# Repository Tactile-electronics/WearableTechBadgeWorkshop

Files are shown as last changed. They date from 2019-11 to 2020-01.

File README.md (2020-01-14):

## Wearable Technology Badge Workshop



Make a small interactive rechargeable wearable badge over 4 weeks to get you started in the world of wearable technology. Designed to give you an understanding of basic fundamentals in electronics, embroidery and coding in the versatile progamming language micropython to control interactive intimate wearables.  We'll use DIY conductive yarn pressure sensors and variants of low cost ESP8266 development boards that can help you deploy all kinds of wearable (and non-wearable) technology.

With this experience you'll be able to prototype and deply wearable tech for art, performance, fashion, product development. It's a chance to share your ideas with peers and meet other members of the DoES Liverpool community and get to know our facilities for the future.

All materials are provided, with extensive workshop notes, reference and resources here plus your own kit featuring an ESP8266 development board, Sublimation printed sensor, single and 6-ring NeoPixels, and a rechargeable battery pack you can for your next project.

Under 16s must be accompanied by a parent or guardian, suitable for ages 12 and up.

### Structure

 1. [Analog Textile Sensor making](#session-1)
 1. [LED & NeoPixel control with ESP8266 and MicroPython](#session-2)
 1. [Analog Sensor & ESP8266](#session-3)
 1. [Advanced ESP8266, sensor & LED control & Wearable Badge constructing](#session-4)

### Session 1

Make & test an analog textile sensor to understand the basics of electrical resistance and the flow of current in a simple circuit.




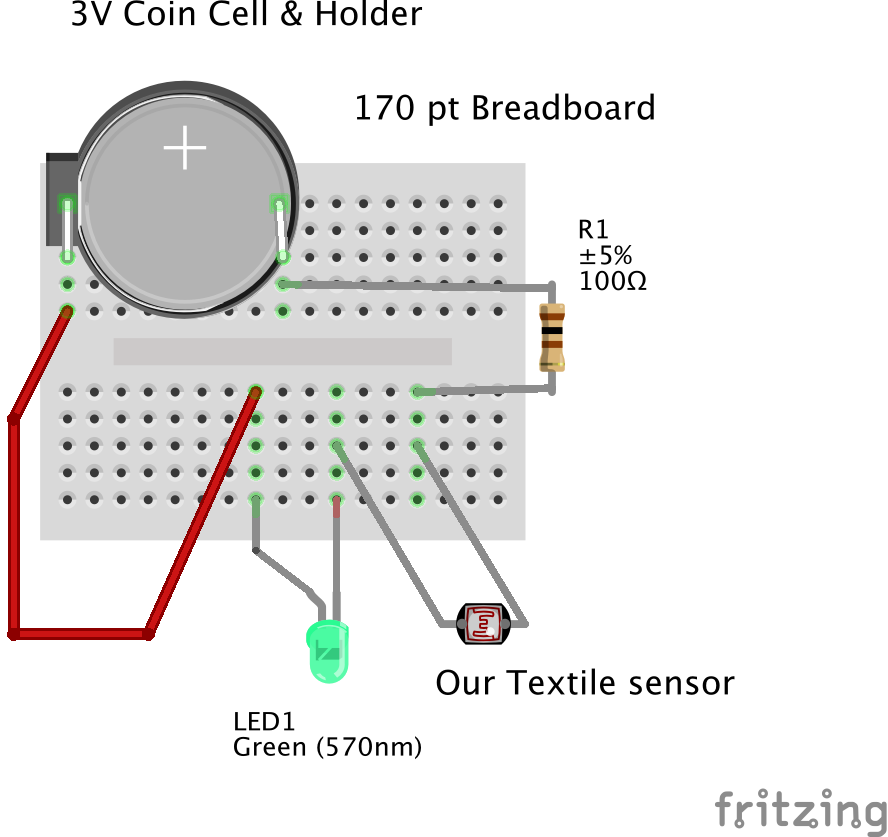
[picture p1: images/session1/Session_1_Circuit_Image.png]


Our breadboard lets us easily connect electronic components and wire of the correct gauge clearly without the components falling out. They are how people prototype a circuit, and quite often you will rewire it in a way that's more robust and permanent or even design and make your own printed circuit boards (PCBs). On these mini 170-point breadboards there are 2 columns of 17 rows of 5 pins. Each 5 pin set on a  row are connected electrically so current flows through components. We generally dont use voltage over 12V when using these breadboards so we never have anything close to mains voltage. We are not even going above 3.7V with our wearables!

Follow the pictures below to make the circuit and compare it with the circuit diagrams provided. That's how you'll find diagrams on the internet and in electronics books, so it's worth having a look at those and doing some further research.

#### Circuit

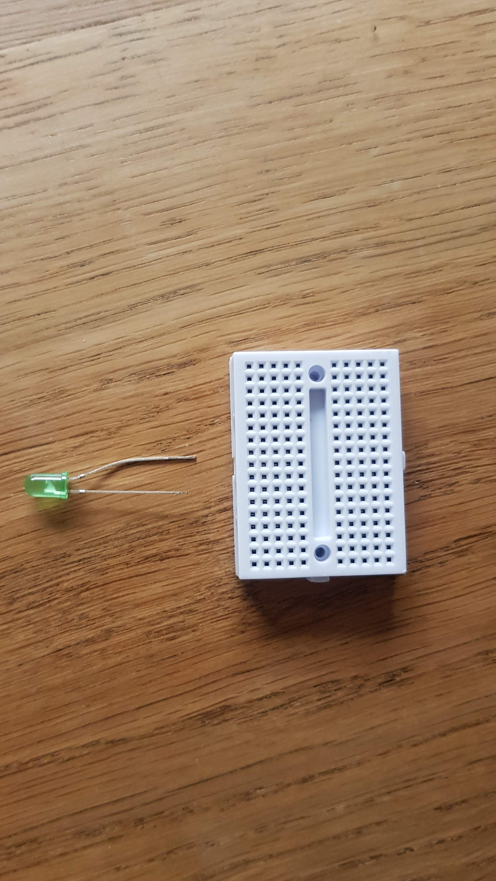
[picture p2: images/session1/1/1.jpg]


Insert your LED. It matters which way the LED goes in; it's got a negative cathode `-` and a positive anode `+` if you get it wrong you can damage it. The long leg of the LED is `+'ve`, the shorter leg, the cathode, is `-'ve'`

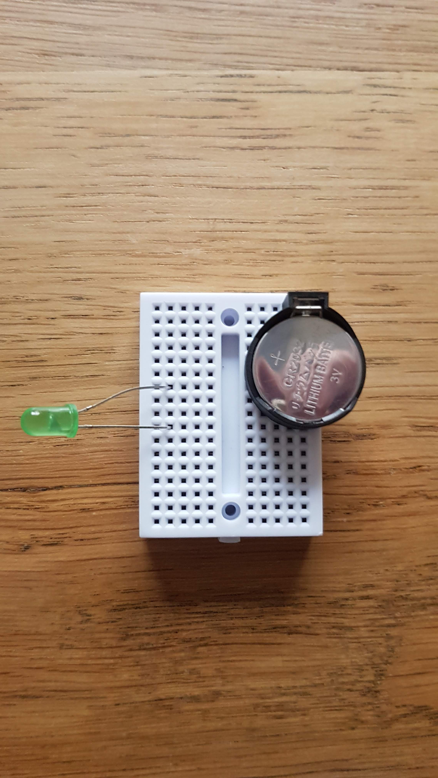
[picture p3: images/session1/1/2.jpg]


Add your coin cell holder and coin cell. Be careful you understand the `+'ve` and `-'ve` cathod and anode. The `+` on the coin cell should be visible facing up, the Flat side of the coin cell holder is `-`

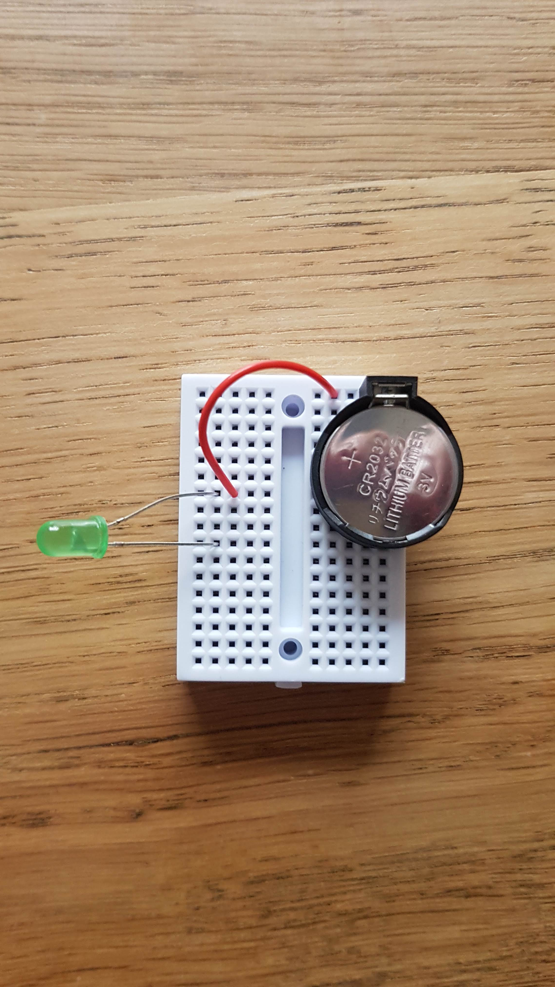
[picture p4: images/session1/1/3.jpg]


Add a red jummper wire connecting the long leg `+` anode of the LED with the `+` anode of the coin cell holder, the pin nearest the flat side of the holder

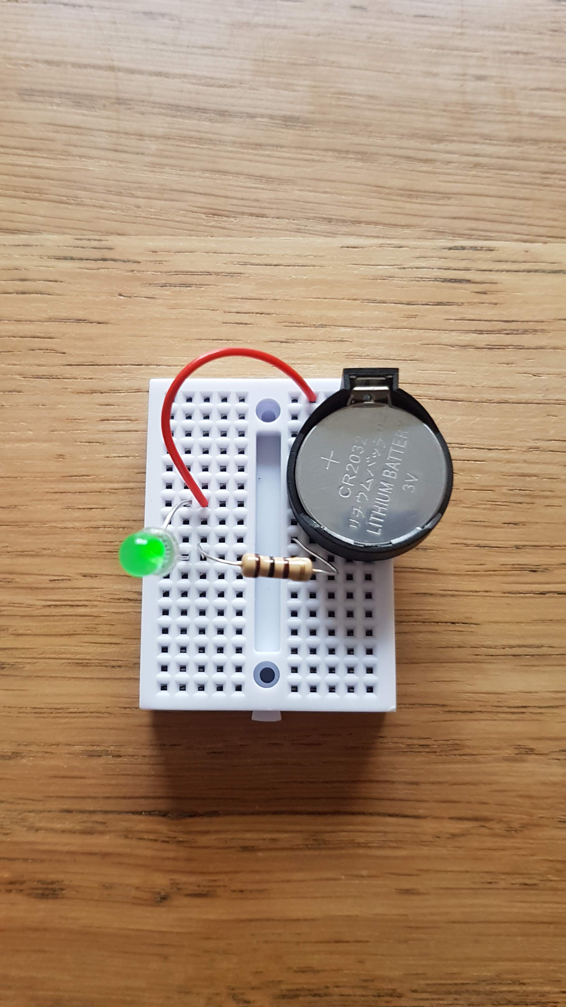
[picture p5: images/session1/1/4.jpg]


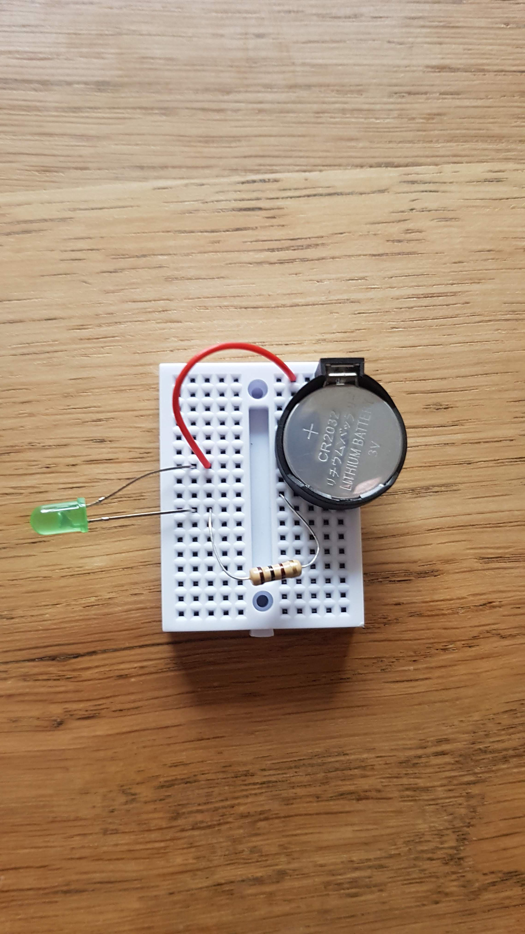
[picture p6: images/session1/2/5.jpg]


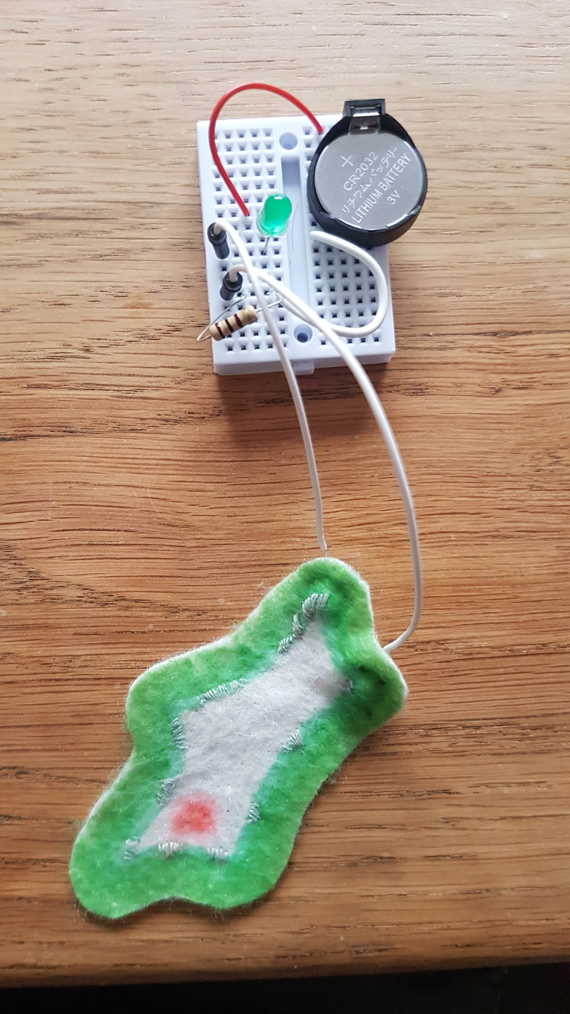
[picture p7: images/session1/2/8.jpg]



Stitch onto the felt with the resistive thread, leaving a long piece on the back of the felt before your first stitch




Make some stitches close together some can be touching but not overlapping or on top of one another


Continue until you have stitched along the back of the design, its fine to leave gaps. Leave a piece trailing at the other end. 




Tie a piece of conductive thread to one end of the stitching
Stitch and add a snap fastener, then repeat at the other side with conductive thread.


Solder wires onto the other side of the snap fasteners.


Clip the fasteners together

#### Component List

Component|No.|Source|Produced|Notes
--|--|--|--|--
170 point<br>mini breadboard|1|DoES|China|For prototyping
3V CR2032 coin cell battery|1|Ebay|
Two Pin Button|1|[Taydae Electronics](https://www.taydaelectronics.com/tact-switch-6-6mm-5mm-through-hole-spst-no.html)|China|simple breadboard compatible button
CR2032-compatible Watch Battery holder|1|[BatteryHolders.com](http://batteryholders.com/part.php?pn=BC2032-E2&original=CR2032&override=CR2032)|China|Easy breadboarding holder
Red Stripped solid core 22AWG wire|1|[Farnell](https://uk.farnell.com/c/cable-wire-cable-assemblies/hook-up-wire?wire-gauge=22awg)|[Alphawire](http://www.alphawire.com/) New Jersey US|Stripped fits into breadboards easily
Green Stripped solid core 22AWG wire|1|[Farnell](https://uk.farnell.com/c/cable-wire-cable-assemblies/hook-up-wire?wire-gauge=22awg)|[Alphawire](http://www.alphawire.com/) New Jersey US|Stripped fits into breadboards easily
Resistor 100 Ohm|1|Ebay|China|Resistor; fits anyway round (polarity doesn't matter)
Resistor 10K Ohm|1|Ebay|China|Resistor; fits anyway round (polarity doesn't matter)

This first step develops the basics of a pressure sensor; we can refer to more complex and accurate sensors and reflect on their usage.

### Further Reading

You can read about an alternative form of pressure sensor using [Velostat](https://www.adafruit.com/product/1361) that Laura made for another workshop using a similar microcontroller [Microbit](https://www.microbit.org/) belwo, that also runs micropython the programming language we are using to control our sensors and LED's.

[Pressure sensor build](https://github.com/DoESLiverpool/what-does-health-look-like/tree/master/pressure-sensor)

### Session 2






Flash LEDs in response to our sensors using micropython on ESP8266

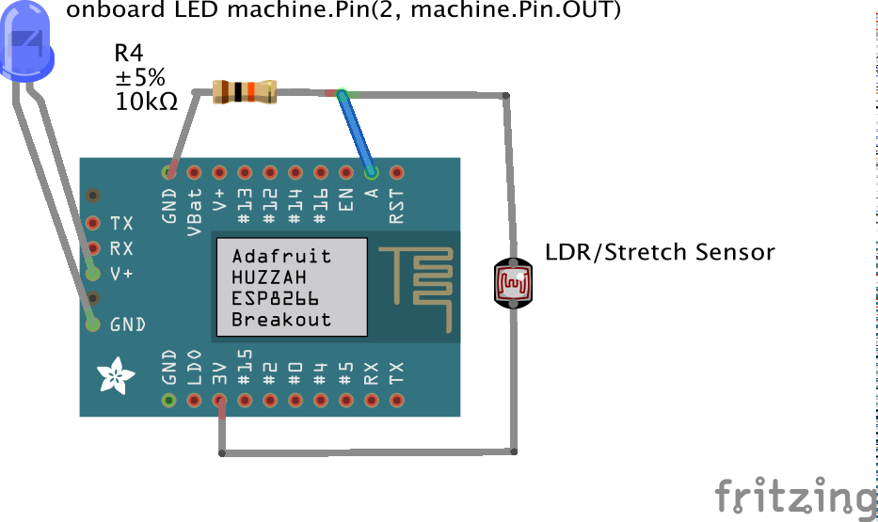
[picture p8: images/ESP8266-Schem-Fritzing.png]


#### Micropython and the ESP8266

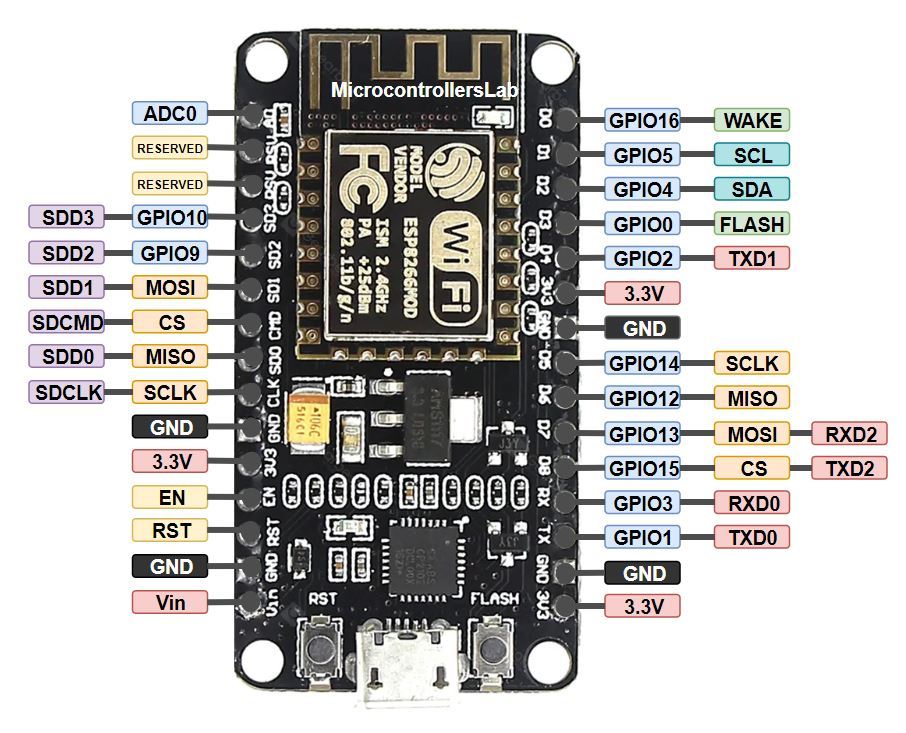
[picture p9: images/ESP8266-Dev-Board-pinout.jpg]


We're using the a few variant breakout boards of the ESP8266 like the WeMos D1 Mini Development Board in the diagram above or the bigger [ESP-12E-CP2102](https://www.ebay.co.uk/itm/Esp8266-Esp-12E-Cp2102-Wifi-Network-Development-Board-Module-For-Node-Mcu-GD/264530529453) variant which you can see above with its `GPIO` pin arrangement. We'll be using these in our workshops and you'll be able to take them home.

You can refer to the [MicroPython tutorial for ESP8266](https://docs.micropython.org/en/latest/esp8266/tutorial/index.html#micropython-tutorial-for-esp8266) for full details, but we've selected.

#### Connecting up

You'll need `CP2102` USB Module drivers to work with our ESP8266's which you can get from our friends at [Shrimping.It](https://shrimping.it/drivers/) and we'll provide them in the workshop from [here](drivers)

Linux distributions include built-in CP2102 drivers, although Linux user accounts may need membership of the 'dialout' or 'serial' permission groups to access the device.

#### Using PUTTY

To get connected on Windows you might be best using PUTTY

Windows Download [PuTTY](https://putty.org/) to connect your ESP8266 to your computer over USB-Serial and be able to send commands to control and set it up.

Linux - Use the built in `screen`, `minicom` or Putty using `$ sudo apt-get install putty` in your Linux Terminal. I'd recommend screen.

Mac - Download [PuTTY](https://putty.org/) or use the built-in `Applications/Terminal` and `screen`

#### Using `screen`

On macos and Linux you can just use a Terminal and `screen`. If your linux doesnt have screen install with `sudo apt-get install screen` or `brew install screen` on a mac after setting up [HomeBrew](https://brew.sh/)

`$ ls /dev/tty*`

to list your usb devices.

`$ screen /dev/device_name baud-rate`
is the general format.

`$ screen -S wearable /dev/tty.SLAB_USBtoUART 115200`

Then press enter and you'll see the python prompt. You are now connected to your ESP8266!

### Micropython Command Walkthrough

In python like we saw earlier, we import the tools we need to do the various things we need, with microbit, most of it is already there.

Get the machine module to control our ins and outs

`import machine`

Lets define a Pin as an output, using the onboard Pin no. 2

`ledPin2 = machine.Pin(2, machine.Pin.OUT)`

This should turn the LED on!

Now try:

`ledPin2.off()`

Annoyingly defining the pin like this means off has no effect, but we can use Signal to abstract away this.

`from machine import Signal`
`Led2 = Signal(ledPin2, invert=True)`

now things will work more intuitively if we use Led2 instead!

`Led2.off()`
`Led2.on()`

Ok now lets read one of our sensors. Wire up following the diagram above.

The ADC (analog to digital conversion) Pin is labelled A0 on your board and we will need the ADC class to make it work

`from machine import ADC`
`adc = ADC(0)`
`adc.read()`

Will return a value. Ok lets get it to read the values until we press `ctrl +c`. We will use a simple loop using `while`

`while True:` press return and you will see `...` and your cursor will indent automatically.

`adc.read()`

Now press return, and you get another indent, return a few time indicates thats the end of that loop and it will then execute the code.

Play with your sensor and watch the numbers change. Cool eh? Bit fast though, lets slow it down with `time`

`import time`

Now we can use `time.sleep(seconds)` to wait before reading the pin again.

```
while True:
    adc.read()
    time.sleep(0.5)
```

Now lets use that to blink our LED

```
while True:
    Led2.on()
    time.sleep_ms(adc.read() * 10)
    Led2.off()
    time.sleep_ms(adc.read() * 10)
```

Ok but higher resistance, bigger stretch or pressue is slowing our flashes. WE can flip it round

```
while True:
    stretch = 500 - (adc.read() *10)
    Led2.on()
    time.sleep_ms(stretch)
    Led2.off()
    time.sleep_ms(stretch)
```

### Making Permanent Changes

You need to make a `main.py` file on the board. To do this you need to write your code and copy it into the command line prompt of the ESP

So copy the text from [main.py](main.py).
Then in your open console for your ESP:

`f = open('main.py', 'w')`

then use **paste mode**: move your cursor to just after the set of 3 quotes (they are essential) and press `ctrl + e` and you will be given a few options: right click paste or shortcut `cmd + v` to paste in your text for the programme. Then finish and call `f.close()` to close and save the file.

```
f.write('''paste_your_text here''')
f.close()
```

Check its there with

`import os`
and
`os.listdir()` to check it's there.

Now reboot, and if your file is correct it will run the `boot.py` script (don't worry about that for now it just sets up the board and python) and then your `main.py` file should run!

We generally prototype code by running it line by line, a bit like having a *conversation* with your board. I like the way that weirdly makes you feel more connected to it and we think it might help you learn.

Then you can write your `main.py` file based on these conversations, have a look at our [`main.py` template](main.py) to see how our 'conversations' we've had here looks as a complete python script. (it is like writing the script of the conversation you've alread had :smile:

### Ampy

There are other methods to upload more complex files you can look at like [ampy](https://github.com/scientifichackers/ampy) so we will try setting this up for you.

 * `ampy --port /dev/MY_PORT_NAME ls` Lists files

 * `ampy --port /dev/MY_PORT_NAME put examples/circle/lights.py` Puts the file on the board

 * `ampy --port /dev/MY_PORT_NAME rm examples/circle/lights.py` Removes the file on the board

### PWM output and Controlling LEDs

We've taken from [this tutorial by Random Nerd Tutorials](https://randomnerdtutorials.com/esp32-esp8266-pwm-micropython/)

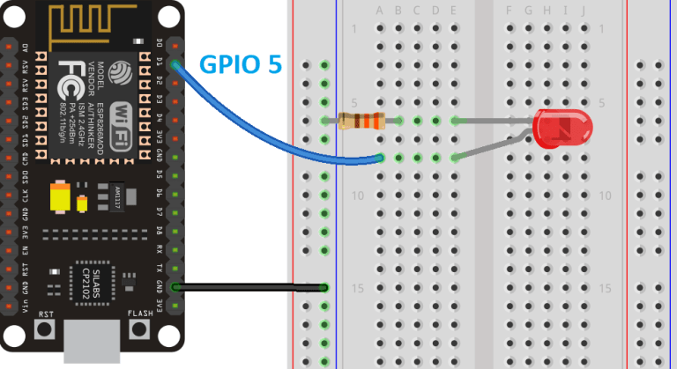
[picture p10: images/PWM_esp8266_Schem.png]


For this example, wire an LED to your ESP board. We’ll wire the LED to `GPIO 5` (marked as `D1` on your board), but you can choose another suitable PWM pin

Here’s the script that changes the LED brightness over time by increasing the duty cycle.

```
from machine import Pin, PWM
from time import sleep

frequency = 5000
led = PWM(Pin(5), frequency)

while True:
    for duty_cycle in range(0, 1024):
    led.duty(duty_cycle)
    sleep(0.005)
```

Also refer to these tutorials
 * [PWM Tutorial](https://docs.micropython.org/en/latest/esp8266/tutorial/pwm.html#pulse-width-modulation)
 * [Fading an LED](https://docs.micropython.org/en/latest/esp8266/tutorial/pwm.html#fading-an-led)

### NeoPixels

To wire up you just connect `3.3V`(marked as `3V3` on your board) to `+VCC` on the neopixel, `GND` (marked `GND` on your board) to `GND` on the neopixel, and `GPIO5` (marked as `D1` on your board to the `IN` or `DIN` on the neopixel. NeoPixels have got all the resistors on board so you wont need to protect your Digital pins when using them.

NeoPixels are addressable RGB LEDs and micropython has a library module just for that! Add the [`lights.py`](https://github.com/cheapjack/WearableTechBadge/blob/master/examples/circle/lights.py) script to your board and with a quick

```
from lights import *
```

You can run this example code from the [NeoPixel MicroPython Guide](https://docs.micropython.org/en/latest/esp8266/tutorial/neopixel.html):

Once the `lights.py` file is on board, re-log on to your board and you can run these commands:

`cycle()`, `bounce()`, `fade()` and `clear()`

There's also a [`main.py`](https://github.com/cheapjack/WearableTechBadge/blob/master/examples/circle/main.py) you can add so they run on booting the board.

Try writing your own combinations of these functions on a loop and try changing the for loops to cycle through colours

```
from machine import Pin
from neopixel import NeoPixel
import time

n = 7 # Set the number of pixels on your NeoPixel
pin = Pin(5, Pin.OUT)   # set GPIO5 (D1) to output to drive NeoPixels
np = NeoPixel(pin, 7)   # create NeoPixel driver on GPIO0 for 7 pixels
np[0] = (255, 255, 255) # set the first pixel to white
np.write()              # write data to all pixels
np[0] = (0, 0, 0) # set the first pixel to nothing (black)
np.write()              # write data to all pixels

def cycle():
    for i in range(4 * n):
        for j in range(n):
            np[j] = (0, 0, 0)
        np[i % n] = (255, 255, 255)
        np.write()
        time.sleep_ms(25)

def bounce():
    for i in range(4 * n):
        for j in range(n):
            np[j] = (0, 0, 128)
        if (i // n) % 2 == 0:
            np[i % n] = (0, 0, 0)
        else:
            np[n - 1 - (i % n)] = (0, 0, 0)
        np.write()
        time.sleep_ms(60)

def fade():
    for i in range(0, 4 * 256, 8):
        for j in range(n):
            if (i // 256) % 2 == 0:
                val = i & 0xff
            else:
                val = 255 - (i & 0xff)
            np[j] = (val, 0, 0)
        np.write()

def clear():
    for i in range(n):
        np[i] = (0, 0, 0)
    np.write()
```

#### Components

Component|No.|Source|Cost|Notes
--|--|--|--|--
Microusb data cable|1|Ebay|£1.20|
NodeMcu-CP2102-ESP8266 Development Board (narrow profile)|1|[AliExpress](https://www.aliexpress.com/item/32665100123.htm)|£1.93|
Jumper Wires|10|Ebay|£1|
Resistor 4.7k Ohm|1|Ebay|£0.50|
Conductive Yarn|1|Various|£1|
Pressure Sensor|1|Various|£1|
Conductive Rubber|1|Various|£1|
Textile Back|1|Various|£1|
TOTAL|||£8.63|

### Session 3







Re-visit our sensor circuit but this time combine with our ESP8266 boards and controlling our LEDs

### Session 4




Fabricate our amoeba shaped wearable badge and assemble everything using a textile pocket to enclose electronics

 * Enclose the ESP circuit in a customisable fabric template

## TODO

 * [x] Re-solder the press studs

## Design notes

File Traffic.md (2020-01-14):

#### Traffic light

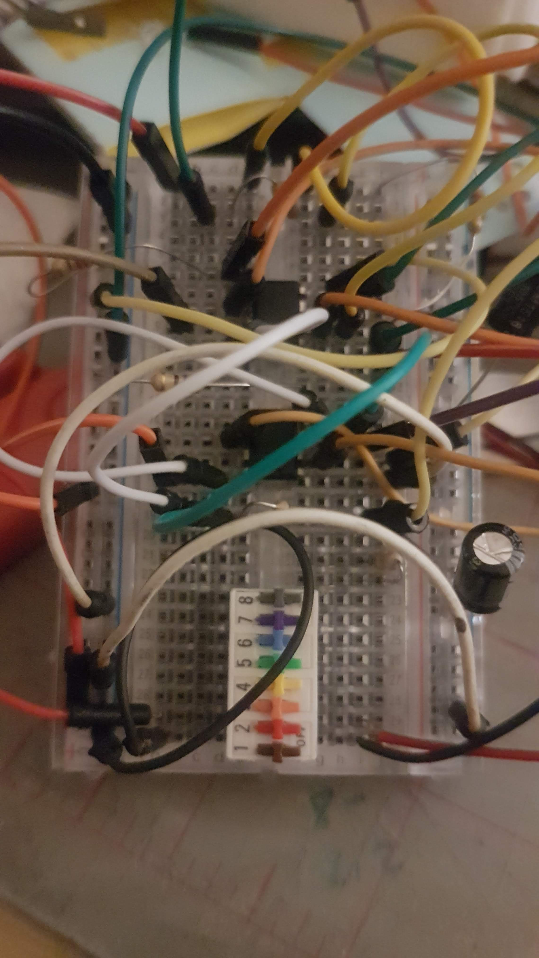
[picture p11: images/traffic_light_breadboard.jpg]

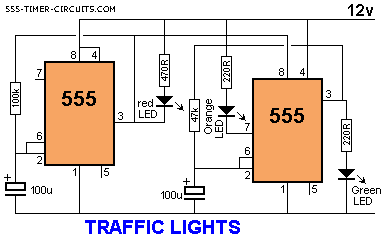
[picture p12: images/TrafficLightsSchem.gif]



Component|No.|Cost|Source|Produced|Notes|SubTotal
--|--|--|--|--|--|--
Mini Breadboard|5|1.196|[Ebay](https://www.ebay.co.uk/itm/5pcs-5x-WHITE-Mini-170-Tie-Point-Solderless-Breadboard-Prototype-Arduino-PIC-PI/262900293129)|China||£5.98
555 Timer Chip|10|0.185|[Ebay](https://www.ebay.co.uk/itm/10-x-NE555P-Timer-DIP-8-IC-Timer-Fast-Delivery-UK-Seller/323925336619)|China||£1.85
9V Battery pack|1||ShrimpingIt surplus|China|Considering replacing with rechargeable LIPO battery
Jumper Wires|40||ShrimpingIt Surplus|
Capacitor 100μF|1||ShrimpingIt surplus|China
Resistor 47K Ohm|1||ShrimpingIt surplus|China
Resistor 470 Ohm|1||ShrimpingIt surplus|China
Resistor 220 Ohm|2||ShrimpingIt surplus|China
Resistor 100k Ohm|1||ShrimpingIt surplus|China

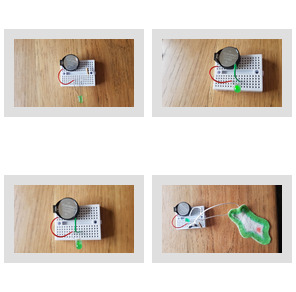
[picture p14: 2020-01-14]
images/session1/2/basic-sensor-circuit-2.jpg

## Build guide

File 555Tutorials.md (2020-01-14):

## 555 Tutorials




Here the 3 of us were interested in exploring physical computing in counterpoint to the previous workshops software layers. We are often frustrated with having to use code to do simple routing or logic that could be done with electronic components. Programming with components means you really understand what components do and how they scale up into Integrated circuits and gives a more intimate understanding of the tech we use.

 * We've used this [555 Timer Learning Site](http://www.555-timer-circuits.com/) to make our circuits

#### 555 Timers

We are using the simple `555` timer chip, one of the most common workhorses of electronics. This integrated circuit creates oscillating square wave signals that can be used to control the flow of voltage in a circuit and so control the logic of say, controlling an LED.

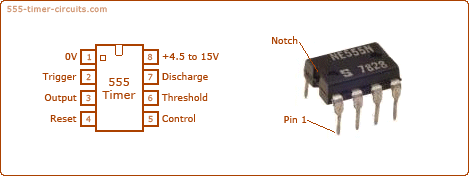
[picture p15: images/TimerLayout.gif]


Find out more on this [555 Timer Circuit website](http://www.555-timer-circuits.com/#circuits)

#### Simple Flasher

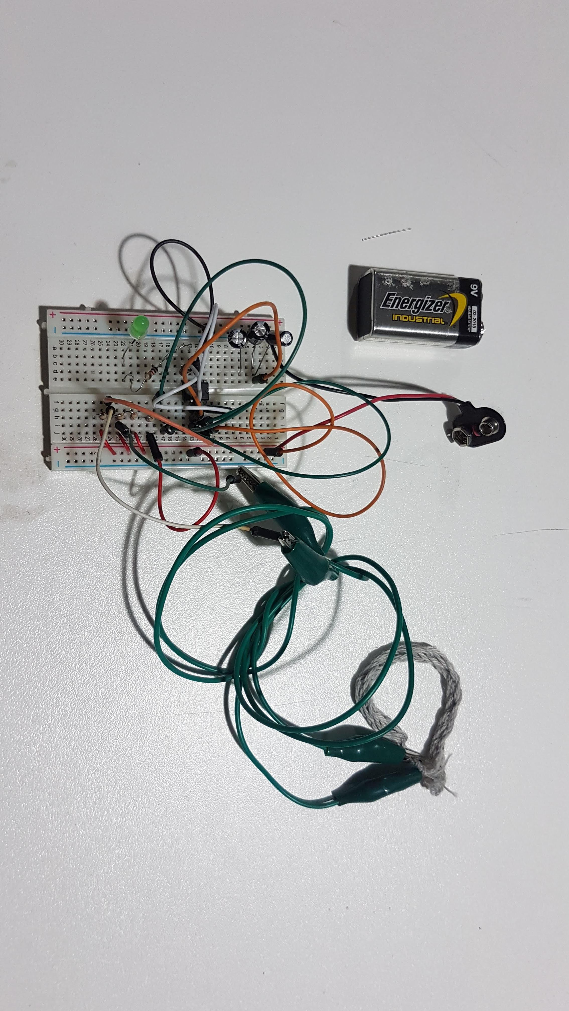
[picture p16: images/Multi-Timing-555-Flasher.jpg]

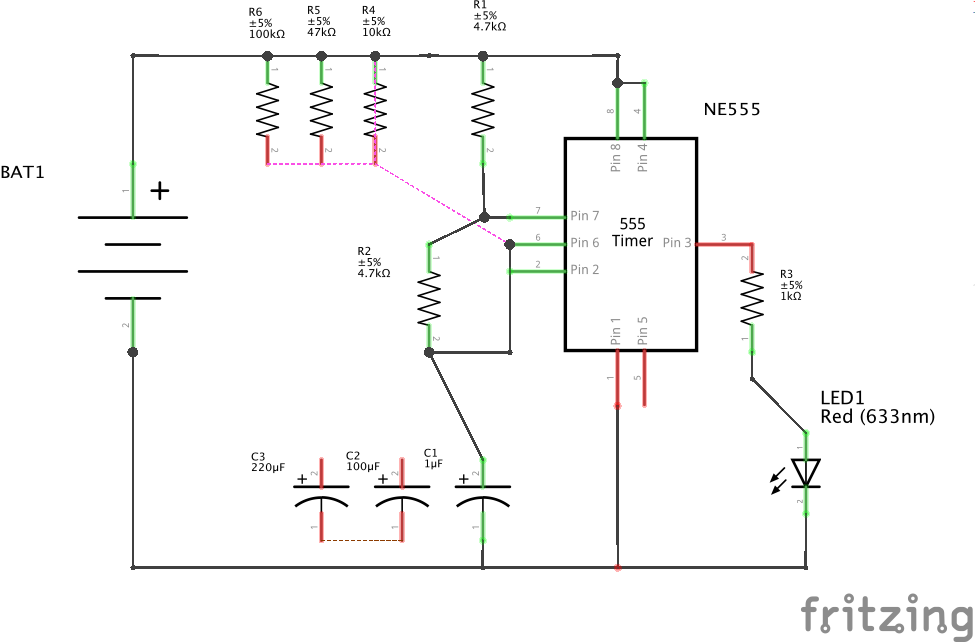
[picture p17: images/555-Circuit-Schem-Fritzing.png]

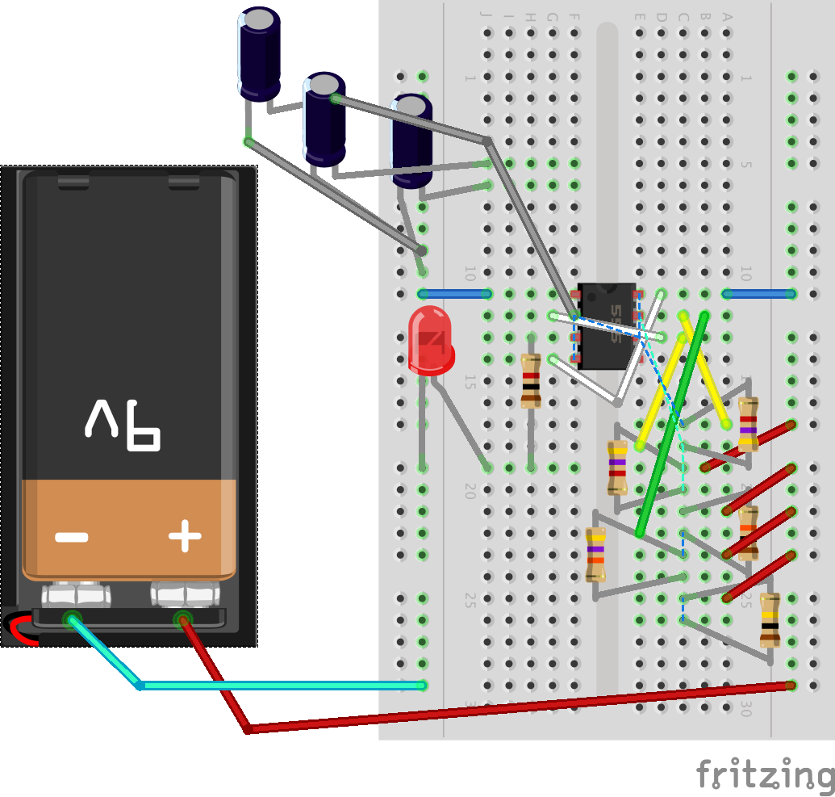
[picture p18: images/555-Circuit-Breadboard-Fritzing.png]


We've made a circuit with an array of capacitors and resistors so you can experiment with the timings

##### Timing LED pulses

 * C1 1µF Capacitor
 * C2 100µF Capacitor
 * C3 220µF Capacitor
 * R1 = 4.7K Ohm
 * R2 = 4.7K Ohm
 * R3 = 1K Ohm
 * R4 = 10K Ohm
 * R5 = 47K Ohm
 * R6 = 100K Ohm

You can work out the timings with this formula

t<sub>on</sub> = 0.69 x C1 x (R1 + R2)
t<sub>off</sub> = 0.69 x C1 x R2

t<sub>on</sub> = Length of high pulse (seconds)
t<sub>off</sub> = Length of low pulse (seconds)
C1 = Capacitance in Farads
R1 = Resistance in Ohms
R2 = Resistance in Ohms

#### Example

t<sub>on</sub>  = 0.69 x 0.0001 x (4700 + 4700) = 0.64 seconds
t on = 0.69 X 0.000220 x (4700 + 4700) = 1.42 seconds

#### Components

Component|No.|Source|Produced|Notes
--|--|--|--|--
300 point Half Breadboard|1|ShrimpingIt surplus|China
9V Battery pack|1|ShrimpingIt surplus|China|Consider replacing with rechargeable LIPO battery
Jumper Wires|9|DoES Surplus|
555 Timer Chip|1|Ebay|China
Capacitor 1μF|1|ShrimpingIt surplus|China
Capacitor 100μF|1|ShrimpingIt surplus|China
Capacitor 220μF|1|ShrimpingIt surplus|China
Resistor 4.7k Ohm|1|ShrimpingIt surplus|China
Resistor 4.7k Ohm|1|ShrimpingIt surplus|China
Resistor 10k Ohm|1|ShrimpingIt surplus|China
Resistor 47k Ohm|1|ShrimpingIt surplus|China
Resistor 100k Ohm|1|ShrimpingIt surplus|China
Conductive Yarn/Rubber/Pressure Sensor|||

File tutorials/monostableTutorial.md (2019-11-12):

---
author: John Hewes
description: 'Electronics Club - 555 Monostable'
keywords: electronics beginner 555 timer monostable timing circuit single pulse
lang: en
title: |
    Electronics Club - 555 Monostable - operation, time period, power-on
    reset, trigger, edge trigger
viewport: 'width=device-width'
---

[Electronics Club{.logo width="125"
height="62"}](https://electronicsclub.info/)

555 Monostable
==============

::: {.clearboth}
:::

[Time period](#timeperiod) \| [Operation](#operation) \|
[Power on reset/trigger](#poweron) \| [Edge trigger](#edgetrigger)

[555 timer IC{.narrow width="74"
height="62"}](https://www.rapidonline.com/texas-instruments-ne555p-bipolar-single-timer-82-0336)

The [555 timer](555timer.htm) IC can be used with a few simple
components to build a monostable circuit which produces a single output
pulse when triggered. It is called a *mono*stable because it is stable
in just *one* state: \'output low\'. The \'output high\' state is
temporary.

::: {.clearboth}
:::

::: {.wrap300}
::: {.box300}
555 monostable output{width="284"
height="54"}

555 monostable output, a single pulse
:::
:::

::: {.wrap300}
::: {.box300}
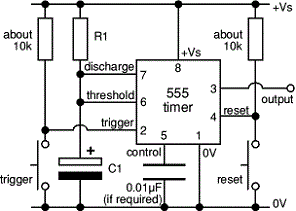
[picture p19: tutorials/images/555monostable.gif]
555 monostable circuit
{width="296"
height="212"}

555 monostable circuit with manual trigger
:::
:::

Recommended book:
[IC 555 Projects](https://www.bookdepository.com/Integrated-Circuit-555-Projects/9780859340472)

::: {#timeperiod .clearboth}
:::

------------------------------------------------------------------------

Monostable Time Period
----------------------

::: {.text}
The duration of the pulse is called the **time period** (T) and this is
determined by resistor R1 and capacitor C1:

  ------------------------------------
  **Time period, T = 1.1 × R1 × C1**
  ------------------------------------

T   = time period in seconds (s)\
R1 = resistance in ohms (ohm{width="12"
height="11"})\
C1 = capacitance in farads (F)\
*The maximum reliable time period is about 10 minutes.*

**Why 1.1?** The capacitor charges to ^2^/~3~ = 67% so it is a bit
longer than the [time constant](capacitance.htm#timeconstant) (R1 × C1)
which is the time taken to charge to 63%.
:::

::: {.right}
::: {.eim}
There is more information about 555 timers and their circuits on the
[Electronics in Meccano](http://www.eleinmec.com/) website.
:::
:::

::: {.clearboth}
:::

### Choosing R1 and C1

**Choose C1 first** because there are relatively few values available.

**Choose R1** to give the time period you need. R1 should be in the
range 1kohm to
1Mohm, so use a fixed
resistor of at least 1kohm in
series if R1 is variable.

**Beware** that electrolytic capacitors do not have accurate values
(errors of least 20% are common) and they tend to leak charge which
increases the time period (especially if you are using a high value
resistor).\
*For example the [Timer Project](p_timer.htm) should have a maximum time
period of 266s (about 4½ minutes), but many electrolytic capacitors
extend this to about 10 minutes!*

::: {.clearboth}
:::

------------------------------------------------------------------------

::: {.flexad}
[]{.underline}
:::

::: {#operation .clearboth}
:::

------------------------------------------------------------------------

Monostable operation
--------------------

::: {.fullwidth}
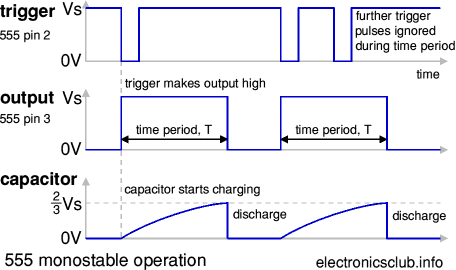
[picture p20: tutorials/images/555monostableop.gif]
555 monostable operation
{.fit width="456"
height="270"}
:::

The timing period is triggered (started) when the **trigger** input (pin
2) is less than ^1^/~3~ Vs, this makes the **output** high (+Vs) and the
capacitor C1 starts to charge through resistor R1. Once the time period
has started further trigger pulses are ignored.

The **threshold** input (pin 6) monitors the voltage across C1 and when
this reaches ^2^/~3~ Vs the time period is over and the **output**
becomes low. At the same time **discharge** (pin 7) is connected
internally to 0V, discharging the capacitor ready for the next trigger.

The **reset** input (pin 4) overrides all other inputs and the timing
may be cancelled at any time by connecting reset to 0V, this instantly
makes the output low and discharges the capacitor. If the reset function
is not required the reset pin should be connected to +Vs directly with
wire or with a resistor of about 10kohm{width="12"
height="11"} (the value isn\'t critical).

::: {.clearboth}
:::

------------------------------------------------------------------------

::: {.flexad}
[]{.underline}
:::

::: {#poweron .clearboth}
:::

------------------------------------------------------------------------

Power-on reset or trigger
-------------------------

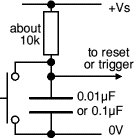
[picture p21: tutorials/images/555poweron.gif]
power-on reset or trigger circuit
{.narrow
width="136" height="138"}

It may be useful to ensure that a monostable circuit is reset or
triggered automatically when the power supply is connected or switched
on. This is achieved by using a capacitor instead of (or in addition to)
a push switch as shown in the diagram.

The capacitor takes a short time to charge, briefly holding the input
close to 0V when the circuit is switched on. A switch may be connected
in parallel with the capacitor if manual operation is also required.

This arrangement is used for the trigger in the
[Timer Project](p_timer.htm).

::: {#edgetrigger .clearboth}
:::

------------------------------------------------------------------------

Edge-triggering
---------------

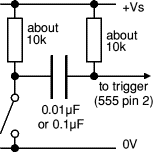
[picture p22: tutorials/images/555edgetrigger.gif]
edge-trigger circuit
{.narrow width="154"
height="152"}

If the trigger input is still less than ^1^/~3~ Vs at the end of the
time period the output will remain high until the trigger is greater
than ^1^/~3~ Vs. This situation can occur if the input signal is from an
on-off switch or sensor.

The monostable can be made **edge triggered**, responding only to
**changes** of an input signal, by connecting the trigger signal through
a capacitor to the trigger input. The capacitor passes sudden changes
(AC) but blocks a constant (DC) signal. For further information please
see the page on [capacitance](capacitance.htm#coupling). The circuit is
\'*negative edge triggered*\' because it responds to a sudden fall in
the input signal.

The resistor between the trigger (pin 2) and +Vs ensures that the
trigger is normally high (+Vs).

------------------------------------------------------------------------

::: {.wrap300}
#### Projects using 555 monostable:

-   [1-10 Minute Timer](https://www.electronicsclub.info/p_timer.htm)
-   [Electronic \'Lock\'](https://www.electronicsclub.info/p_lock.htm)
-   [Light-sensitive Alarm](https://www.electronicsclub.info/p_lightalarm.htm)

Rapid Electronics: [NE555
timer](https://www.rapidonline.com/texas-instruments-ne555p-bipolar-single-timer-82-0336)

**Next page:** [555 Bistable](https://www.electronicsclub.info/555bistable.htm)

**Also see:** [555 Timer](555timer.htm) \| [Astable](https://www.electronicsclub.info/555astable.htm) \|
[Buffer](https://www.electronicsclub.info/555buffer.htm)

:::

::: {.wrap300}
::: {.ad320}
[]{.underline}
:::
:::

::: {#footer}

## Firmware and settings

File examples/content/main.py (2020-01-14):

from switch import Switch
from machine import Pin
from machine import Timer
from neopixel import NeoPixel
import time
import lights2

n = 8

button_green = Pin(14, Pin.IN, Pin.PULL_UP)
button_red = Pin(12, Pin.IN, Pin.PULL_UP)
my_switch_green = Switch(button_green)
my_switch_red = Switch(button_red)
neopixel_pin = Pin(5, Pin.OUT)
np = NeoPixel(neopixel_pin, n)
level = 0
brightdiv = 4 # fraction 1/4
steps = 6
max_level = 8
for i in range(n):
    np[i] = (255 // brightdiv, 0, 255 // brightdiv)
np.write()
time.sleep_ms(60)
rgb_start_discontent = [160, 60, 30]
rgb_end_discontent = [40, 25, 15]
rgb_sparkle_discontent = [25, 255, 0]
rgb_start_content = [200, 55, 0]
rgb_end_content = [135, 120, 0]
rgb_sparkle_content = [255, 255, 255]
rgb_blue = [0, 0, 255]
rgb_red = [255, 0, 0]

while True:

    my_switch_green_new_value = False
    my_switch_red_new_value = False
 
    # Disable interrupts for a short time to read shared variable
    irq_state = machine.disable_irq()
    if my_switch_green.new_value_available:
        my_switch_green_value = my_switch_green.value
        my_switch_green_new_value = True
        my_switch_green.new_value_available = False
    if my_switch_red.new_value_available:
        my_switch_red_value = my_switch_red.value
        my_switch_red_new_value = True
        my_switch_red.new_value_available = False

    machine.enable_irq(irq_state)
 
    # If my switch had a new value, print the new state
    if my_switch_green_new_value:
        if my_switch_green_value:
            print("Green Switch Opened")
        else:
            print("Green Switch Closed")

    if my_switch_red_new_value:
        if my_switch_red_value:
            print("Red Switch Opened")
        else:
            print("Red Switch Closed")

    if (my_switch_green_new_value and not my_switch_green_value) and (my_switch_red_new_value and not  my_switch_red_value):
        level = 0
    elif (my_switch_green_new_value and not my_switch_green_value) and level < max_level:
        level += 1
    elif (my_switch_red_new_value and not my_switch_red_value) and level > -1 * max_level:
        level -= 1

    if level < 0:
        lights2.sparkle(level, brightdiv, steps, max_level, rgb_start_discontent, rgb_end_discontent, rgb_sparkle_discontent)
    elif level > 0:
        lights2.smooth(level, brightdiv, steps, max_level, rgb_start_content, rgb_end_content, rgb_sparkle_content)
    else:
        lights2.sparkle(level, brightdiv, steps, max_level, rgb_red, rgb_red, rgb_sparkle_content)
  

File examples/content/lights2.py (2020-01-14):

from machine import Pin
from neopixel import NeoPixel
import time
import urandom

n = 8
pin = Pin(5, Pin.OUT)   # set GPIO5 (D1) to output to drive NeoPixels
np = NeoPixel(pin, 8)   # create NeoPixel driver on GPIO0 for 7 pixels

def cycle():
    for i in range(4 * n):
        for j in range(n):
            np[j] = (0, 0, 0)
        np[i % n] = (255, 255, 255)
        np.write()
        time.sleep_ms(25)

def bounce():
    for i in range(4 * n):
        for j in range(n):
            np[j] = (0, 0, 128)
        if (i // n) % 2 == 0:
            np[i % n] = (0, 0, 0)
        else:
            np[n - 1 - (i % n)] = (0, 0, 0)
        np.write()
        time.sleep_ms(60)

def fade():
    for i in range(0, 4 * 256, 8):
        for j in range(n):
            if (i // 256) % 2 == 0:
                val = i & 0xff
            else:
                val = 255 - (i & 0xff)
            np[j] = (val, 0, 0)
        np.write()

def clear():
    for i in range(n):
        np[i] = (0, 0, 0)
    np.write()

def sparkle(level, brightdiv, steps, max_level, rgb_start, rgb_end, rgb_sparkle):

    for x in range(n):
        if sparkling(abs(level)):
            np[x] = (rgb_sparkle[0] // brightdiv, rgb_sparkle[1] // brightdiv, rgb_sparkle[2] // brightdiv)
        else:
            np[x] = get_colour(rgb_start, rgb_end, abs(level), max_level, brightdiv)
            

    np.write()
    time.sleep_ms(6)

def smooth(level, brightdiv, steps, max_level, rgb_start, rgb_end, rgb_sparkle):

    selected = []

    for x in range(n):
        if sparkling(abs(level)):
            np[x] = (rgb_sparkle[0] // brightdiv, rgb_sparkle[1] // brightdiv, rgb_sparkle[2] // brightdiv)
            selected.append(1)
        else:
            np[x] = get_colour(rgb_start, rgb_end, abs(level), max_level, brightdiv)
            selected.append(0)

    for x in range(n):
        for y in range(steps):
            if selected[x]:
                np[x] = (
                    255 // brightdiv + (y * (1 - (1 // brightdiv)) // steps),
                    255 // brightdiv + (y * (1 - (1 // brightdiv)) // steps),
                    255 // brightdiv + (y * (1 - (1 // brightdiv)) // steps),
                )
        np.write()
        time.sleep_ms(6)
        for y in range(steps):
            if selected[x]:
               np[x] = (
                    255 // brightdiv + ((steps - y) * (1 - (1 // brightdiv)) // steps),
                    255 // brightdiv + ((steps - y) * (1 - (1 // brightdiv)) // steps),
                    255 // brightdiv + ((steps - y) * (1 - (1 // brightdiv)) // steps),
                )
        np.write()
        time.sleep_ms(6)

# Less or more likely to return True, based on the sparkle_chance.
# sparkle_chance of 0 means 0% chance of returning True.
# sparkle_chance of 255 means 100% chance of returning True.
def sparkling(sparkle_chance):
    return sparkle_chance > 0 and sparkle_chance >= randint(1, 256)

def randint(min, max):
    span = max - min + 1
    div = 0x3fffffff // span
    offset = urandom.getrandbits(30) // div
    val = min + offset
    return val

def static_rainbow(brightdiv):
    np[7] = (255 // brightdiv, 0, 0)
    np[6] = (148 // brightdiv, 0, 211 // brightdiv)
    np[5] = (75 // brightdiv, 0, 130 // brightdiv)
    np[4] = (0, 0, 255 // brightdiv)
    np[3] = (0, 255 // brightdiv, 0)
    np[2] = (255 // brightdiv, 255 // brightdiv, 0)
    np[1] = (255 // brightdiv, 127 // brightdiv, 0)
    np[0] = (255 // brightdiv, 0, 0)
    np.write()

def get_colour(rgb_start, rgb_end, level, max_level, brightdiv):
    rgb_out = [0, 0, 0]
    for y in range(3):
        rgb_out[y] =  (rgb_start[y] + ((rgb_end[y] - rgb_start[y]) * level // max_level)) // brightdiv
    return rgb_out

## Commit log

2019-11-12 added timer layout image
2019-11-28 added notes on main.py making and the sttructure of workshops and added the Fritzing files.
    [555-Circuit.fzz, ESP8266_Sensor.fzz]
2019-12-10 made main.py even simpler to get started with a voltage divider
2019-12-10 added pwm
2019-12-18 added a PWM & NeoPixel tutorial
2019-12-19 added details for the CP2102 drivers from shrimping.it
2019-12-28 Debounce working (https://selfhostedhome.com/debouncing-buttons-in-micropython/)
2020-01-14 recent changes to first session and images
    [555-Circuit.fzz, ESP8266_Sensor.fzz, Session_1_Circuit.fzz]
